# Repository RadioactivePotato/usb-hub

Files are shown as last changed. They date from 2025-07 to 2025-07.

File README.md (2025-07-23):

# usb-hub

# About
This is a 4 port USB 2.0 hub, it has a reverse voltage diode in case the computer sends too much voltage and also has decoupling capacitors to protect the other USB ports. 

# Images

<details>
<summary>Schematic (click to expand)</summary>

| Schematic |
|-----------|
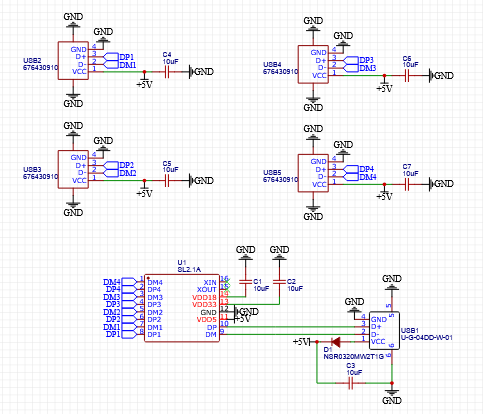
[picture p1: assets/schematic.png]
Schematic
|  |

</details>

| PCB | 3D Preview | Case |
|-----|---|---|
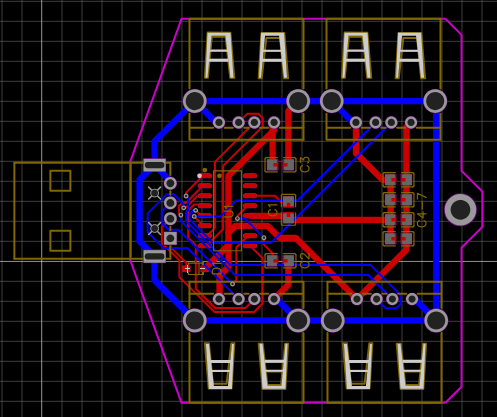
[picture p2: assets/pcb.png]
PCB
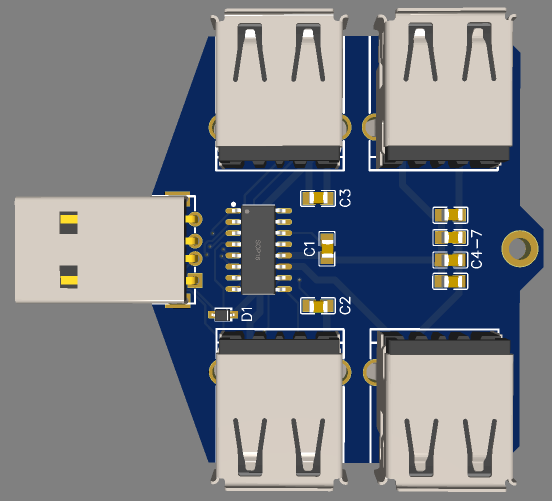
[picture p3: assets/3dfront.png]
3D-Front
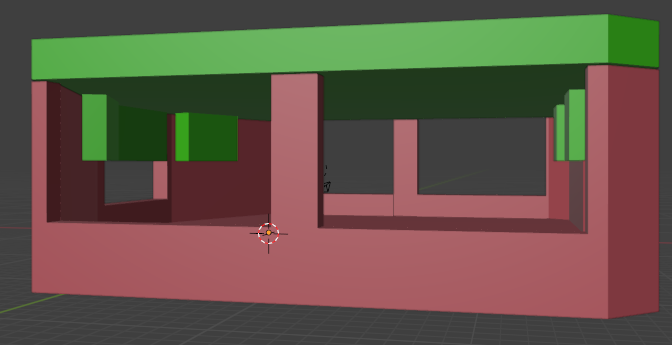
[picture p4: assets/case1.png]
Case1
|  |  | 
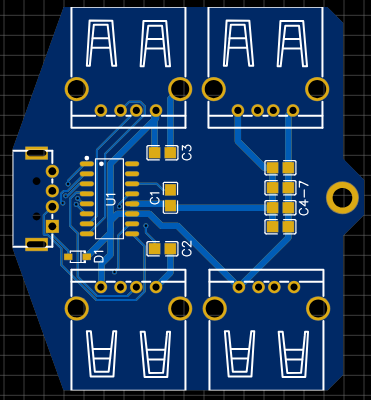
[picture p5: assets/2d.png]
3D
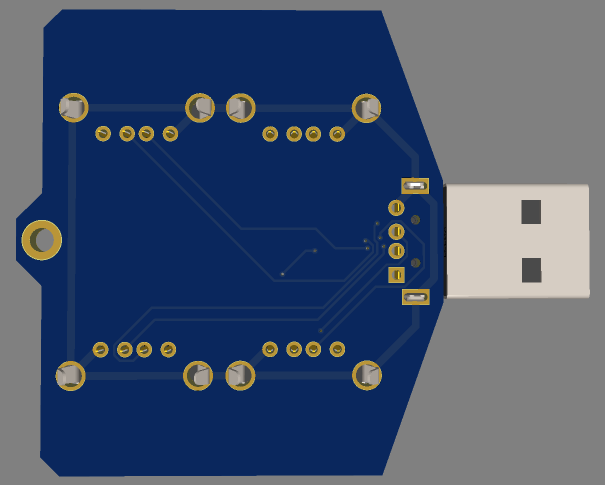
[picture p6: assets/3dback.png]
3D-Back
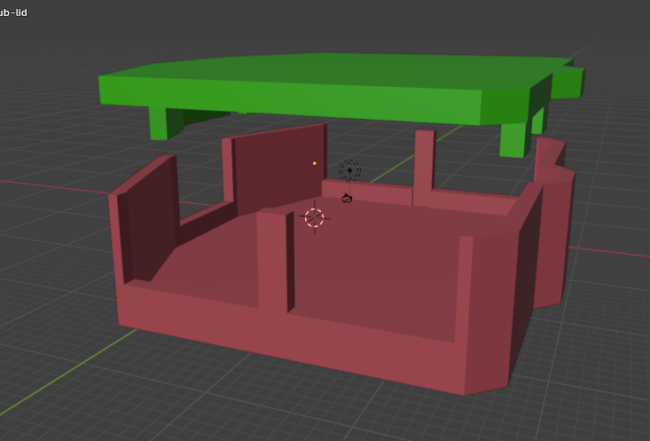
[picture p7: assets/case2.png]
Case2
|  |  |  |

# BOM



# PCB: 1.5USD

<br>

A badge of a Cerberus and a raccoon laughing together, with the text "HIGHWAY" and "HACK CLUB" beside them.

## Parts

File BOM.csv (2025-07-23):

LCSC# | Description | Quantity | MOQ | Extended Price($) | Product Link
C15850 | 25V 10uF X5R ±10% 0805 Multilayer Ceramic Capacitors MLCC - SMD/SMT ROHS | 20 | 20 | 0.22 | https://lcsc.com/product-detail/multilayer-ceramic-capacitors-mlcc-smd-smt_samsung-electro-mechanics-cl21a106kaynnne_C15850.html
C48192 | 20V 500mV@900mA 1A SOD-323 Schottky Diodes ROHS | 10 | 10 | 0.5 | https://lcsc.com/product-detail/schottky-diodes_onsemi-nsr0320mw2t1g_C48192.html
C192893 | SOP-16 USB HUB Controllers ROHS | 5 | 5 | 1.31 | https://lcsc.com/product-detail/usb-hub-controllers_corechips-sl2-1a_C192893.html
C98125 | 1A USB 2.0 1 4P Male Type-A Through Hole USB Connectors ROHS | 5 | 5 | 0.34 | https://lcsc.com/product-detail/usb-connectors_korean-hroparts-elec-u-g-o4dd-w-1_C98125.html
C2346 | USB 2.0 1 4P Female Type-A Through Hole USB Connectors ROHS | 10 | 10 | 0.37 | https://lcsc.com/product-detail/usb-connectors_jing-extension-of-the-electronic-co-901-211a1021d10100_C2346.html
PCB |  | 5 | 5 | 1.5 | https://jlcpcb.com

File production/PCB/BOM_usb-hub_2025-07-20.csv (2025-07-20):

ID | Name | Designator | Footprint | Quantity | Manufacturer Part | Manufacturer | Supplier | Supplier Part | Price
1 | M3 | U3 | M3 | 1
2 | USB A/F 90° Outside the buckle straight foot | USB2,USB3,USB4,USB5 | USB-A-TH_USB-M-1_C2346 | 4 | 901-211A1021D10100 | 精拓金 | LCSC | C2346 | 0.04
3 | 10uF | C5,C6,C1,C2,C3,C4,C7 | C0805 | 7 | CL21A106KAYNNNE | SAMSUNG(三星) | LCSC | C15850 | 0.011
4 | NSR0320MW2T1G | D1 | SOD-323_L1.8-W1.3-LS2.5-RD | 1 | NSR0320MW2T1G | onsemi(安森美) | LCSC | C48192 | 0.05
5 | SL2.1A | U1 | SOP-16_L10.0-W3.9-P1.27-LS6.0-BL | 1 | SL2.1A | CoreChips(和芯润德) | LCSC | C192893 | 0.261
6 | U-G-04DD-W-01 | USB1 | USB-A-TH_U-G-04WD-W-01 | 1 | U-G-O4DD-W-1 | 韩国韩荣 | LCSC | C98125 | 0.088

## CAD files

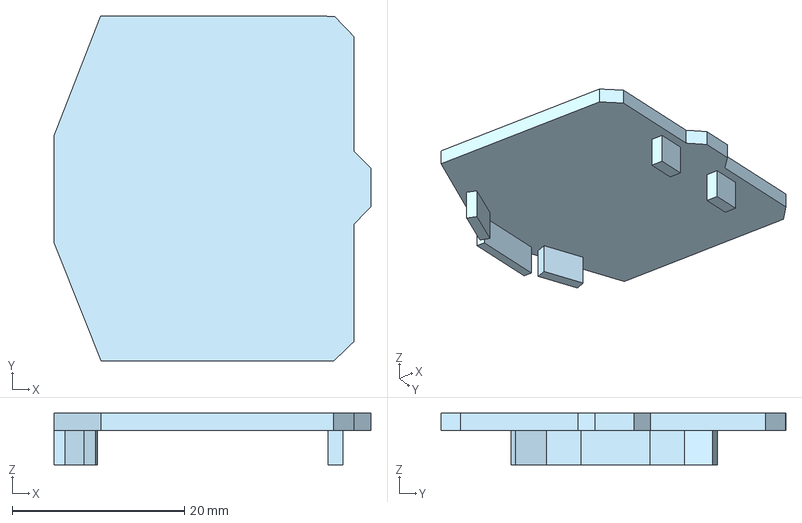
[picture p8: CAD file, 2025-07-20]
cad/lid.step
36.8 x 40.0 x 6.00 mm

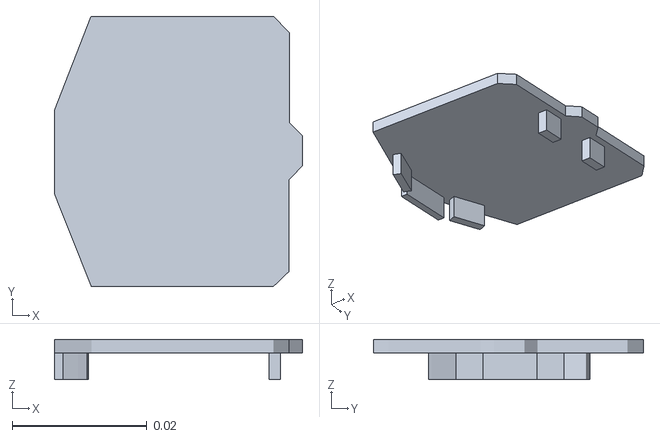
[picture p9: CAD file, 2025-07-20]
production/usb-hub-lid.stl
0.0368 x 0.04 x 0.006

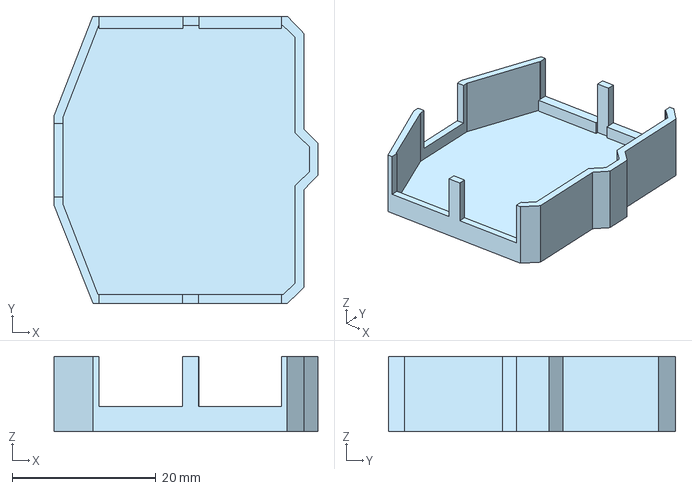
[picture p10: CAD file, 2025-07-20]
cad/base.step
36.8 x 40.0 x 10.5 mm

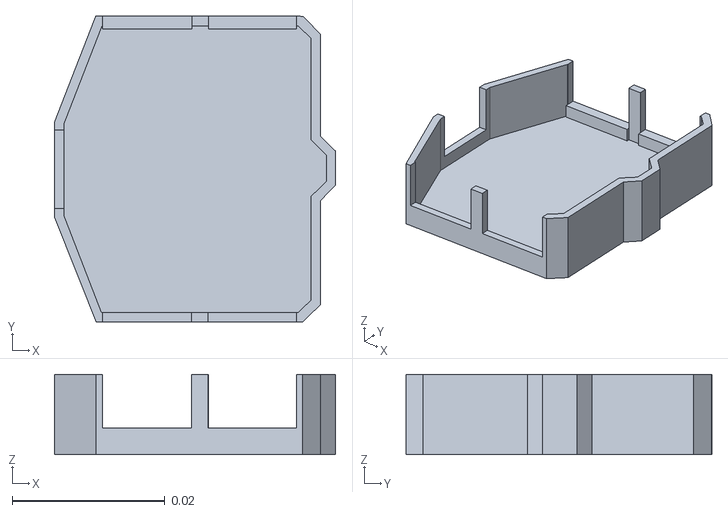
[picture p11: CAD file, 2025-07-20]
production/usb-hub-base.stl
0.0368 x 0.04 x 0.0105

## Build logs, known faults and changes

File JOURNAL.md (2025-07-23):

---
title: "krunch's usb-hub"
author: "slack: krunch"
description: "A 4 Port USB 2.0 Hub "
created_at: "2025-07-19"
---

# July 19 - Schematic and Parts (2 hour)

I designed the schematic today, the IC I am using is the [CoreChips SL2.1A](https://lcsc.com/product-detail/USB-HUB-Controllers_CoreChips-SL2-1A_C192893.html), it supports up to 4 extra USB connection.

I also added a diode at 5V input from the USB-A male connector to prevent backpower.



I originally chose a USB-A female connector that have 2 ports, but I realised that might be too heavy and might break the USB port on my laptop.

So I chose one with only 1 port and used 4 of them.



**Time spent this session: 2 hours**

# July 20 (Morning) - PCB Layout (1.5 hours)

Today I made the PCB layout, I wanted to make it as compact as possible so I decided to put 2 usb ports on each side, and to keep it as short as possible to avoid breaking the laptop's USB port. 

I also wanted to be able to hang this on a keychain/lanyard to I made a plated M3 hole at the end of the USB hub.



For the 5V and ground traces, I made them to be 0.8mm thick, which should be fine for 2.5A to 3.5A (1oz copper), which is more than enough for a USB hub.



And I routed most of the ground traces on the back.



The traces around the IC is a bit tricky to wire up, but with a few vias it looks good now.

**Time spent this session: 1.5 hours**

# July 20 (Afternoon) - Case (2 hours)

I made the case today, the case is printed in 2 parts, the base and the lid, the lid snaps onto the base with these notches





The PCB sits on the edges and the base have a bit of space to allow the through-hole componants to sit on.



In the front of the case, the USB male connector will be held together by the lid.

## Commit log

2025-07-20 case file name
2025-07-20 case journal
2025-07-20 gerber update
2025-07-23 updated bom
2025-07-23 updated bom.csv + readme
    [BOM.csv]
